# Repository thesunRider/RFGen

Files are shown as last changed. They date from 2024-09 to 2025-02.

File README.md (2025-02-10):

# RFGen




This is an open source DIY Square wave generator. There are two versions included: 
- Blue pill - (1Hz - 960Mhz)
- Atmega328p/Arduino (1Hz - 250Mhz)

### Schematics:

Arduino version
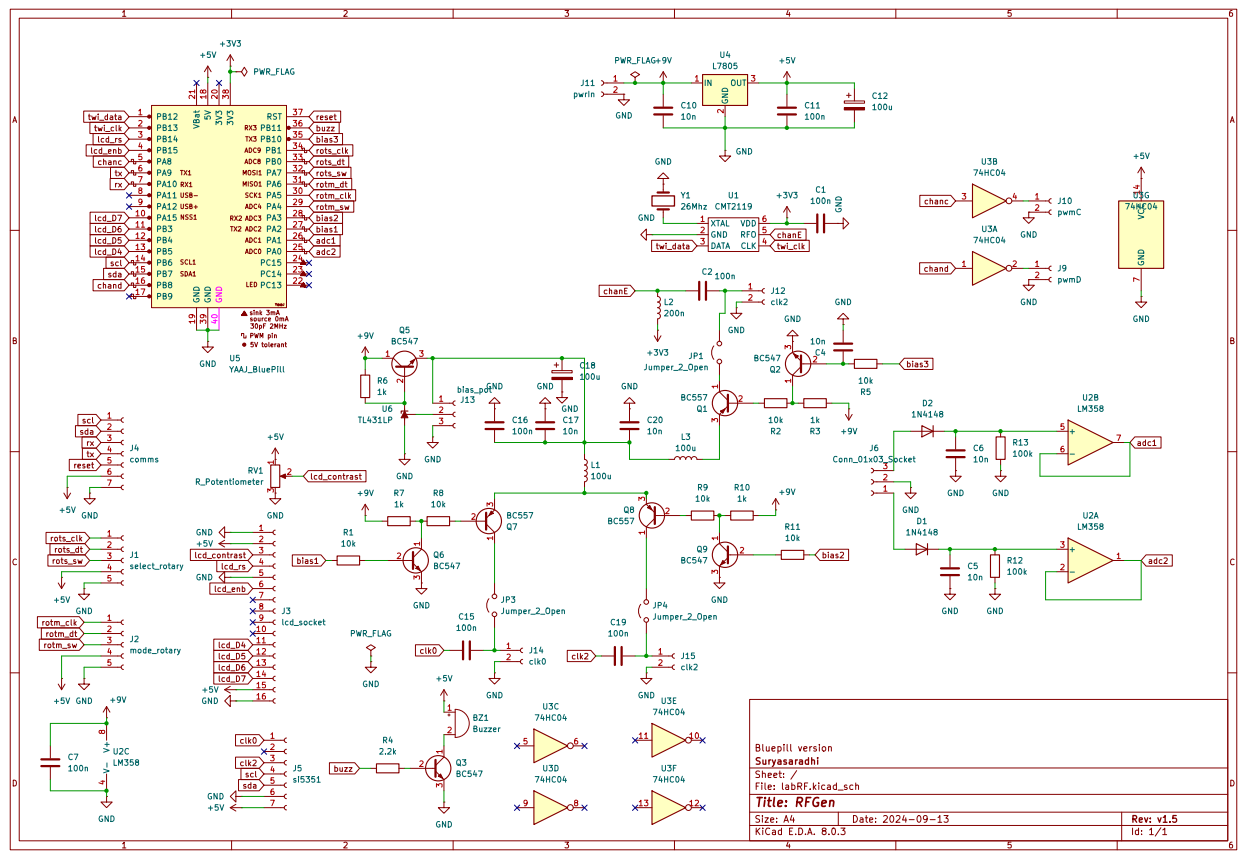
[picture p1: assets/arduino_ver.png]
arduino

Bluepill version
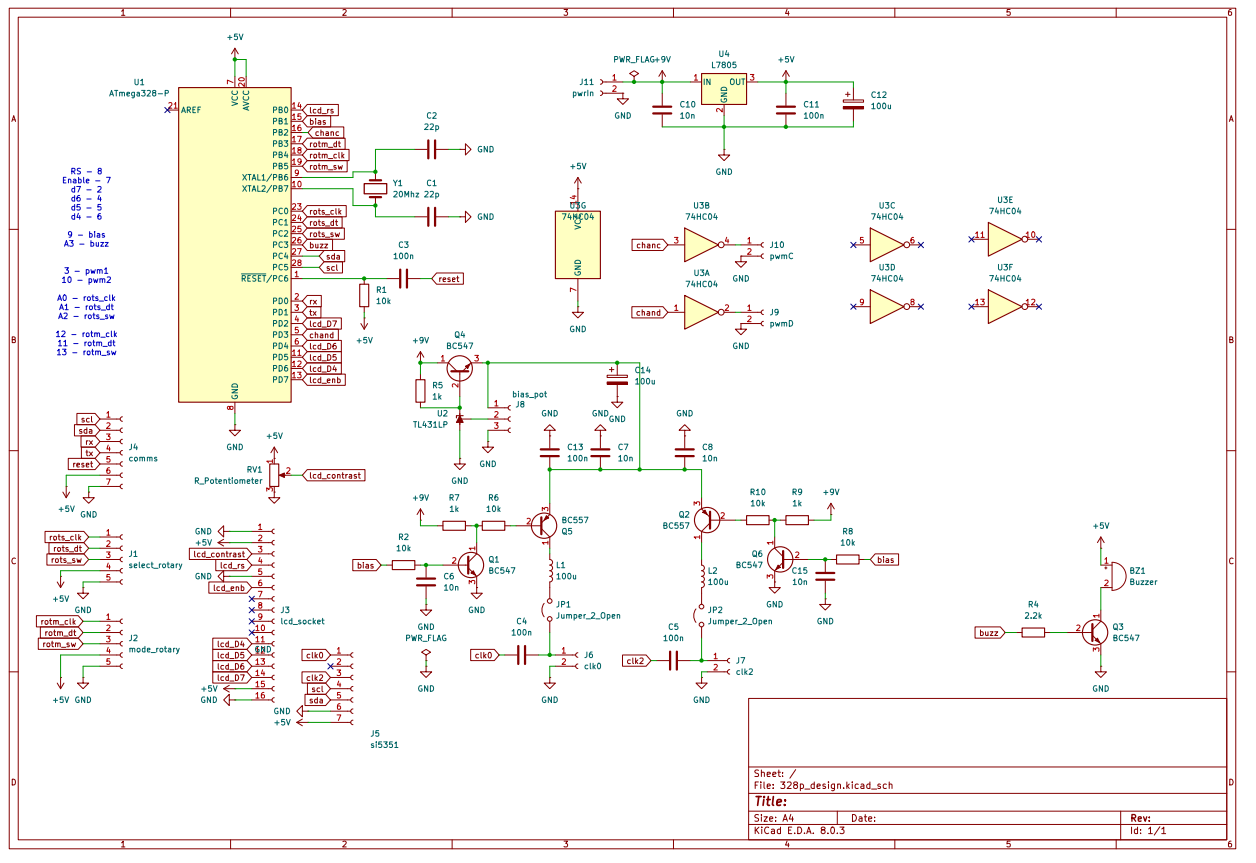
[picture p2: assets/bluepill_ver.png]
bluepill


- Si5351 - Channel A,B (1Khz - 250Mhz)
- CMT2119A - Channel E (only for bluepill version: 250Mhz - 960Mhz)

# Demo
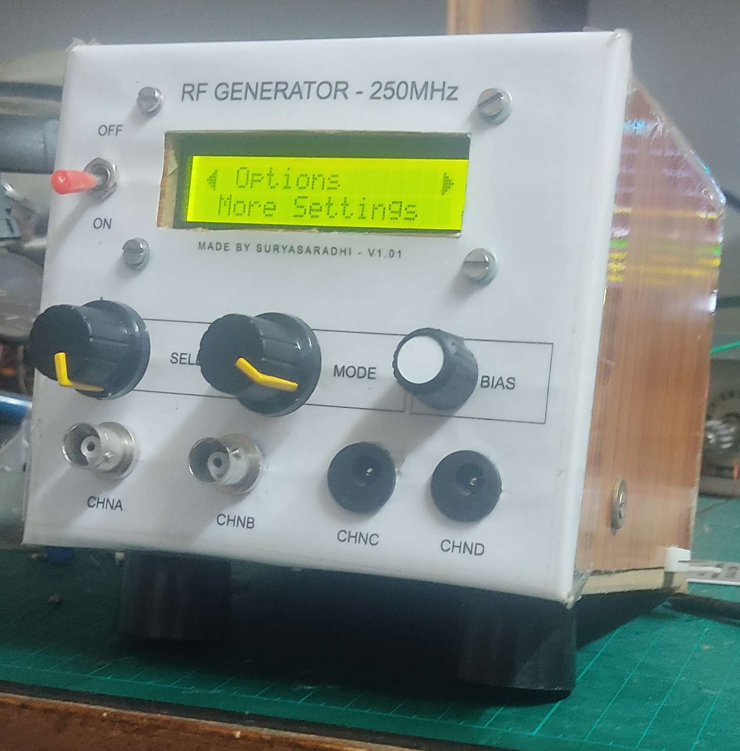
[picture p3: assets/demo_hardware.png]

Demo Video 

https://github.com/user-attachments/assets/bd40d5bd-5a4e-4a5a-9730-a542df9f6650

# Installation

- Upload 328p schematics for an Arduino based generator.
- Upload bluepill schematic for Bluepilll based generator.

> Gerber files attatched with kicad designs

# Usage

There is a bias tee included for these channels whose bias can be adjusted by the attached external potentiometer. 

Supply 9V on the power input, this is regulated to 5v by l7805

# Development

To program a soldered bluepill via USB kindly power off the device before connecting the USB. SInce UART pins are exposed you can program it via those headers too.

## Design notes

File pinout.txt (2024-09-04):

1   2   3   4   5
RX  RST TX SCL SDA

atmega

RS - 8
Enable - 7
d7 - 2
d6 - 4
d5 - 5
d4 - 6

9 - bias
A3 - buzz

3 - pwm1
10 - pwm2

A2,A1,A0
11,12,13

---- ALL PINS USED --------

LCD_RS  - 
LCD_E  - 
LCD_D4  - 
LCD_D5  - 
LCD_D6  - 
LCD_D7  - 
CLK 
DT
SW
CLK
DT
SW
WAV1
WAV2
BIASSWITCH
SCL - 
SDA - 
BUZZER
0 - RX
1 - TX
<-ADD->
TWO MORE switch

-> Total - 20

##PRGRAMMER PINS##
RX
RST
TX
SCL
SDA

LCD R/W  - ground
LCD VSS  - ground
LCD VDD  - 5V

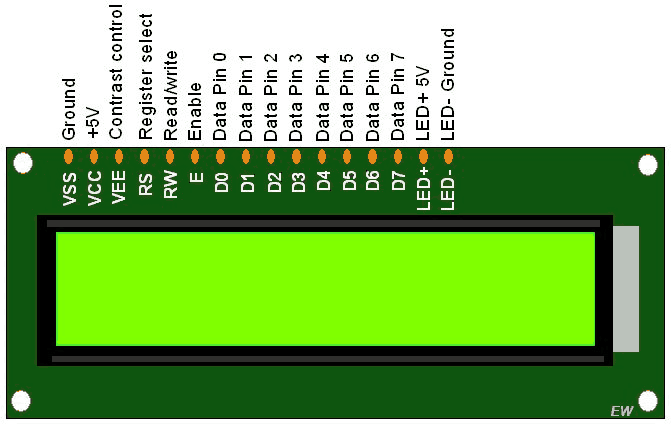
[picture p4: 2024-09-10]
pinouts/LCD16x2 Pins.webp

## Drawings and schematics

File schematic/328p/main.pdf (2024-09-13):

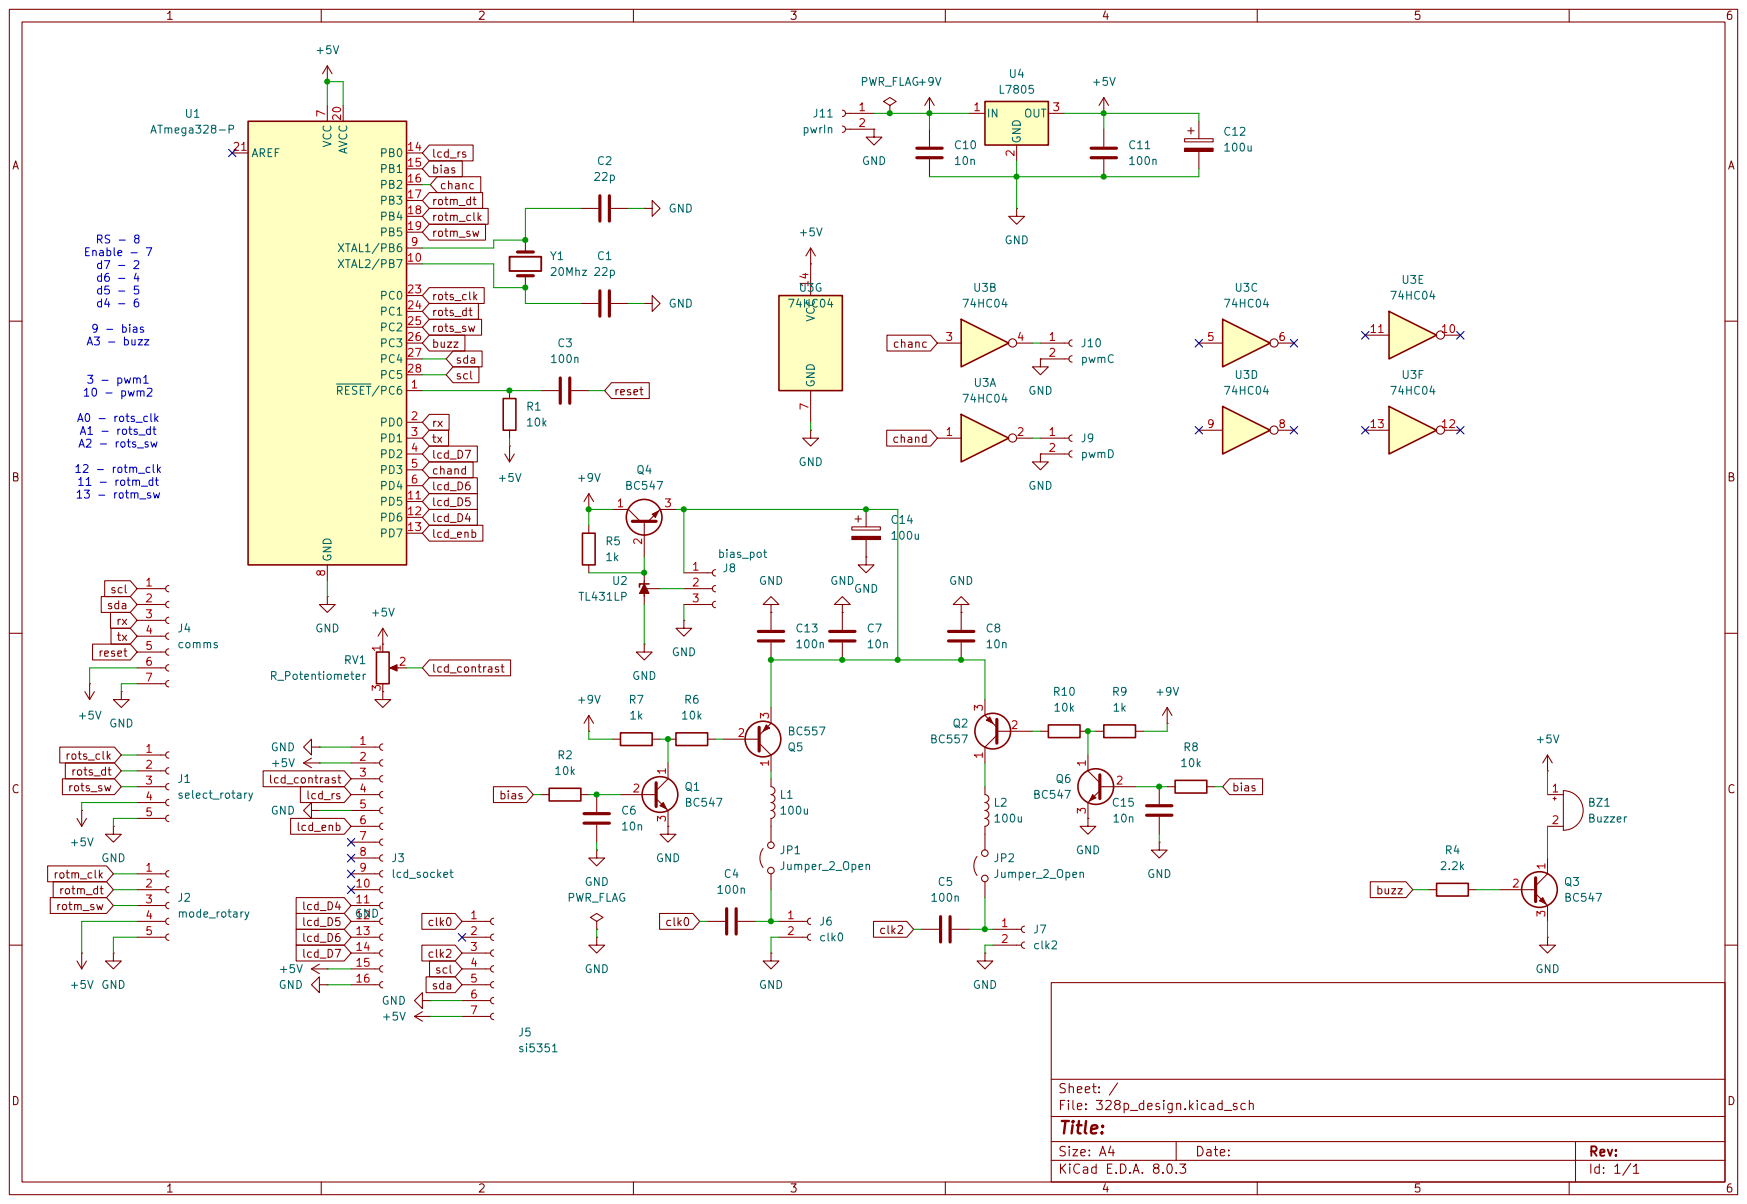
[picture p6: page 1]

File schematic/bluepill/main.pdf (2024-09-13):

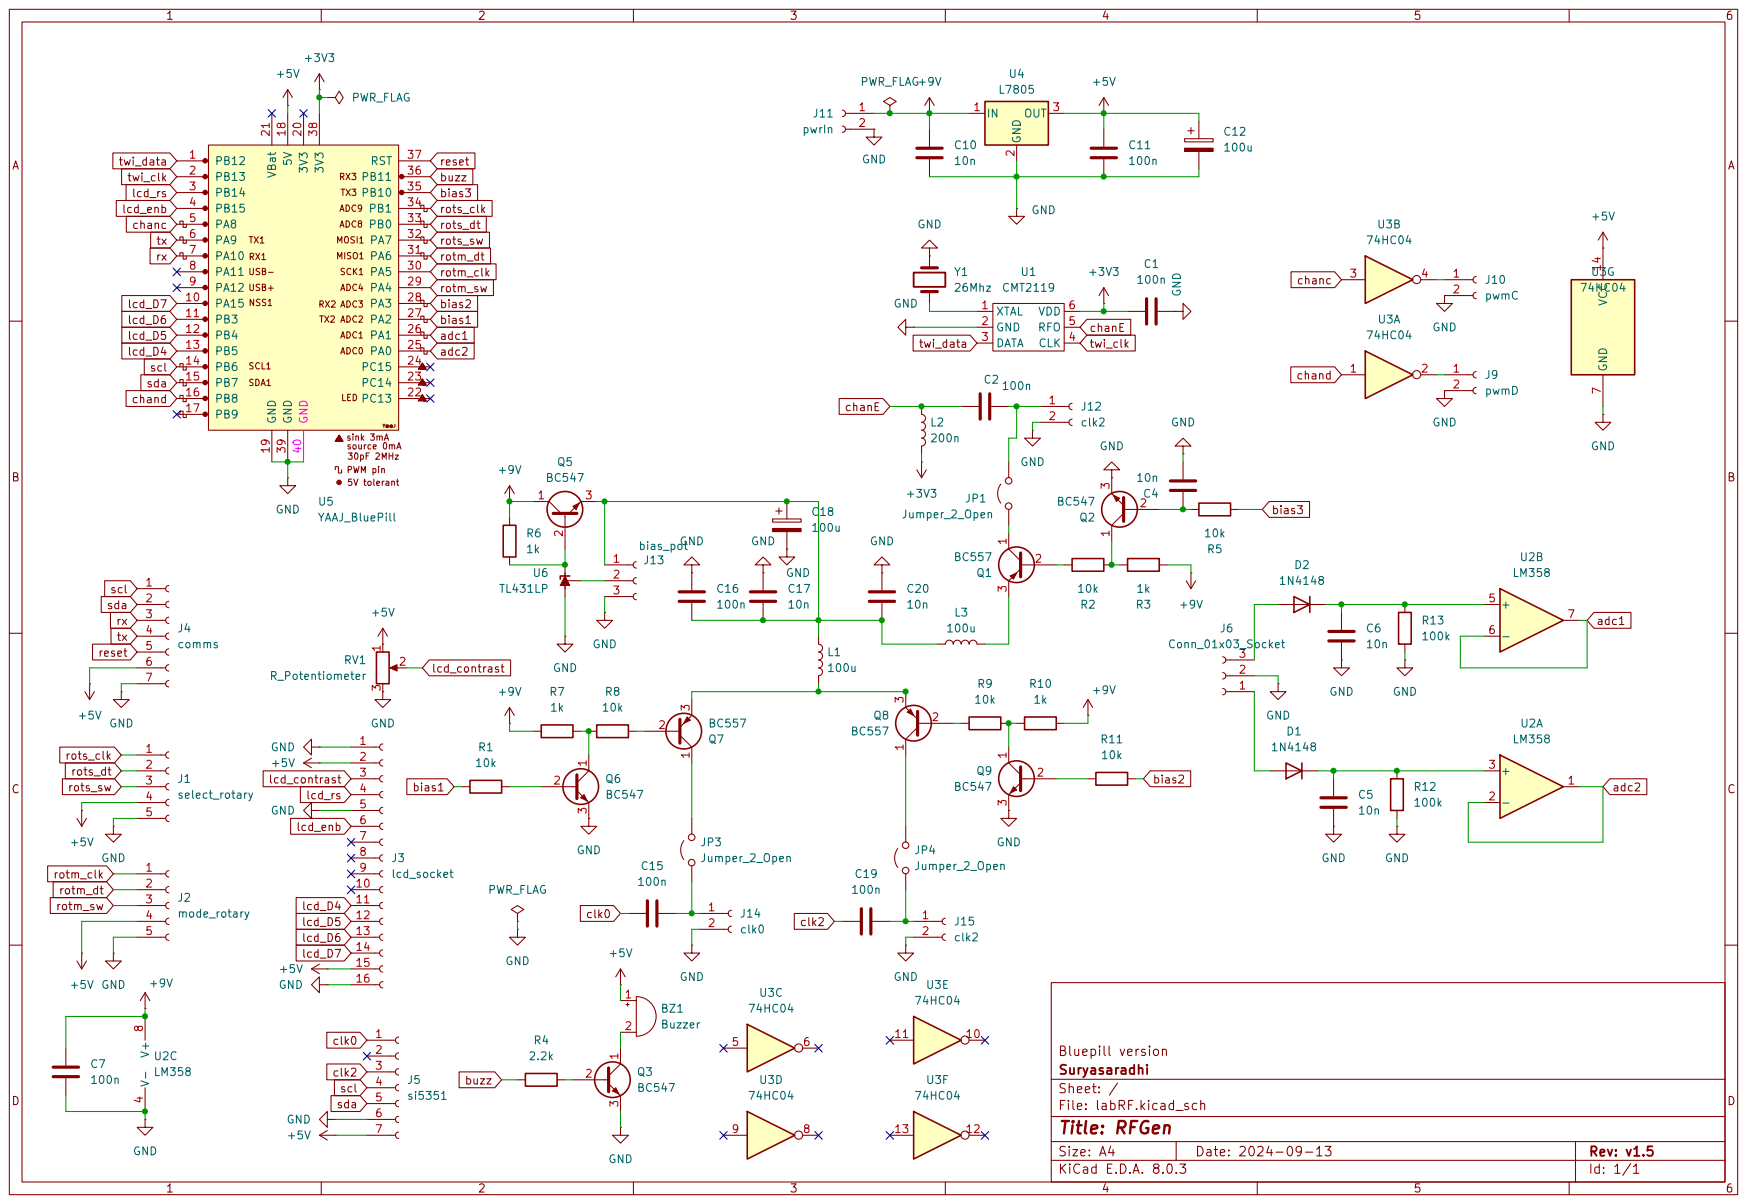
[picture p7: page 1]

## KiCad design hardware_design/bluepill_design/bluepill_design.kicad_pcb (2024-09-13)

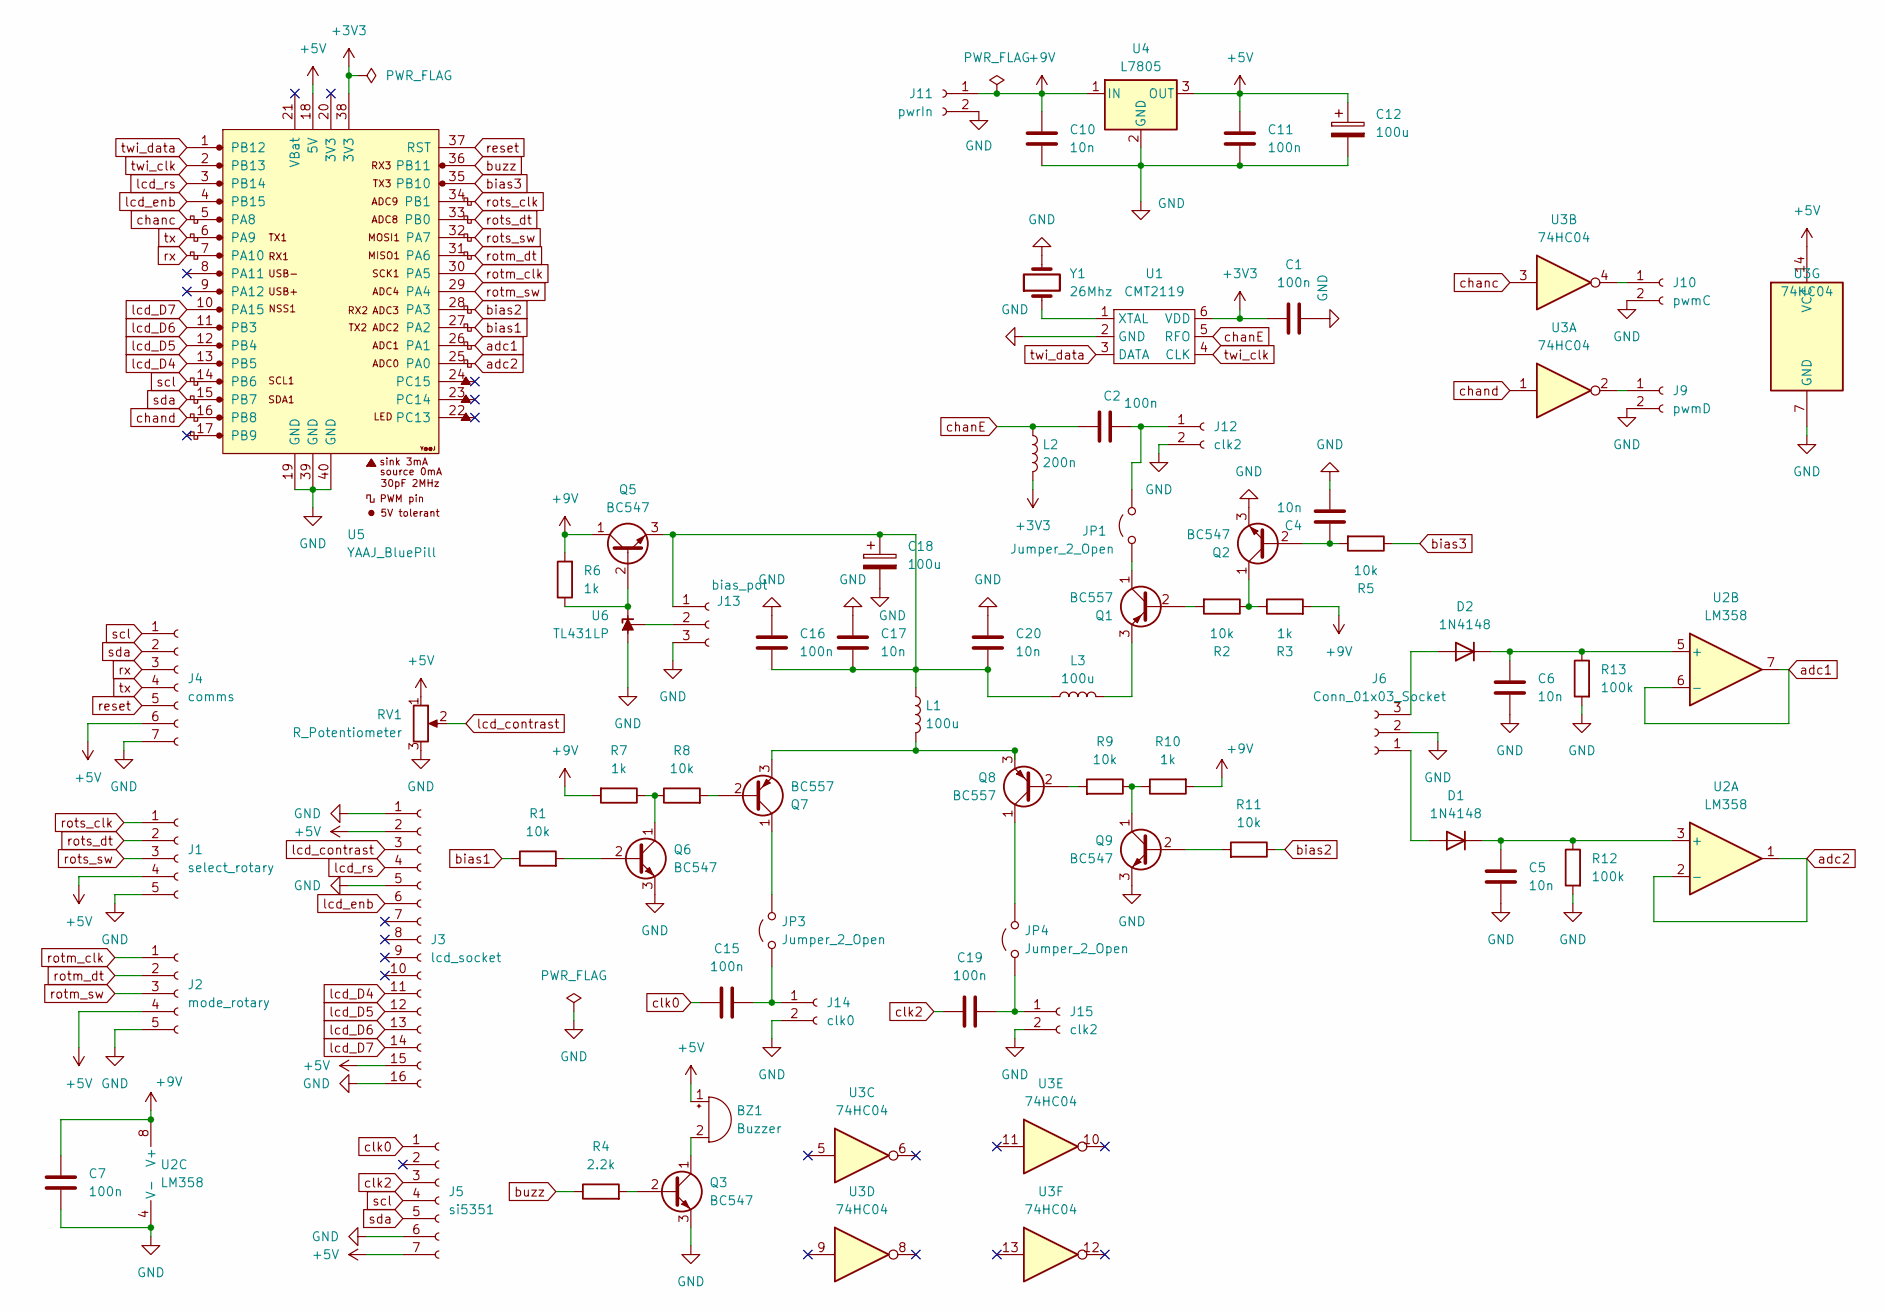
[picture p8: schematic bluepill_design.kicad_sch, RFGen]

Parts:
BZ1: Buzzer; Buzzer_D14mm_H7mm_P10mm
C1, C2, C7, C11, C15, C16, C19: 100n; C_Disc_D5.0mm_W2.5mm_P2.50mm
C4, C5, C6, C10, C17, C20: 10n; C_Disc_D5.0mm_W2.5mm_P2.50mm
C12, C18: 100u; CP_Radial_D8.0mm_P5.00mm
D1, D2: 1N4148; D_DO-35_SOD27_P7.62mm_Horizontal
J1: select_rotary; PinHeader_1x05_P2.54mm_Vertical
J2: mode_rotary; PinHeader_1x05_P2.54mm_Vertical
J3: lcd_socket; PinHeader_1x16_P2.54mm_Vertical
J4: comms; PinHeader_1x07_P2.54mm_Vertical
J5: si5351; PinHeader_1x07_P2.54mm_Vertical
J6: Conn_01x03_Socket; PinHeader_1x03_P2.54mm_Vertical
J9: pwmD; PinHeader_1x02_P2.54mm_Vertical
J10: pwmC; PinHeader_1x02_P2.54mm_Vertical
J11: pwrIn; PinHeader_1x02_P2.54mm_Vertical
J12, J15: clk2; PinHeader_1x02_P2.54mm_Vertical
J13: bias_pot; FanPinHeader_1x03_P2.54mm_Vertical
J14: clk0; PinHeader_1x02_P2.54mm_Vertical
JP1, JP3, JP4: Jumper_2_Open; PinHeader_1x02_P2.54mm_Vertical
L1, L3: 100u; L_Toroid_Vertical_L14.7mm_W8.6mm_P5.58mm_Pulse_KM-1
L2: 200n; L_Toroid_Vertical_L14.7mm_W8.6mm_P5.58mm_Pulse_KM-1
Q1, Q7, Q8: BC557; TO-92_Inline
Q2, Q3, Q5, Q6, Q9: BC547; TO-92_Inline
R1, R2, R5, R8, R9, R11: 10k; R_Axial_DIN0207_L6.3mm_D2.5mm_P10.16mm_Horizontal
R3, R6, R7, R10: 1k; R_Axial_DIN0207_L6.3mm_D2.5mm_P10.16mm_Horizontal
R4: 2.2k; R_Axial_DIN0207_L6.3mm_D2.5mm_P10.16mm_Horizontal
R12, R13: 100k; R_Axial_DIN0207_L6.3mm_D2.5mm_P10.16mm_Horizontal
RV1: R_Potentiometer; Potentiometer_Bourns_3386P_Vertical
U1: CMT2119; SOT-23-6_Handsoldering
U2: LM358; DIP-8_W7.62mm
U3: 74HC04; DIP-14_W7.62mm
U4: L7805; TO-220-3_Vertical
U5: YAAJ_BluePill; YAAJ_BluePill_2
U6: TL431LP; TO-92_Inline
Y1: 26Mhz; Crystal_HC49-U_Vertical

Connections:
+3V3: C1.2, L2.2, U1.6 (VDD), U5.38 (3V3)
+5V: BZ1.1 (+), C11.2, C12.1, J1.4, J2.4, J3.2, J3.15, J4.6, J5.7, RV1.1, U3.14 (VCC), U4.3 (OUT), U5.18 (5V)
+9V: C7.2, C10.2, J11.1, Q5.1 (C), R3.2, R6.2, R7.2, R10.2, U2.8 (V+), U4.1 (IN)
GND: C1.1, C4.2, C5.2, C6.2, C7.1, C10.1, C11.1, C12.2, C16.1, C17.1, C18.2, C20.1, J1.5, J2.5, J3.1, J3.5, J3.16, J4.7, J5.6, J6.2, J9.2, J10.2, J11.2, J12.2, J13.3, J14.2, J15.2, Q2.3 (E), Q3.3 (E), Q6.3 (E), Q9.3 (E), R12.2, R13.2, RV1.3, U1.2 (GND), U2.4 (V-), U3.7 (GND), U4.2 (GND), U5.19 (GND), U5.39 (GND), U5.40 (GND), U6.2 (A), Y1.2
unnamed: BZ1.2 (-), Q3.1 (C)
unnamed: D1.2 (A), J6.1
unnamed: C5.1, D1.1 (K), R12.1, U2.3 (+)
unnamed: D2.2 (A), J6.3
unnamed: C6.1, D2.1 (K), R13.1, U2.5 (+)
unnamed: J9.1, U3.2
unnamed: J10.1, U3.4
unnamed: C2.2, J12.1, JP1.1 (A)
unnamed: C16.2, C17.2, C18.1, C20.2, J13.1, L1.1, L3.1, Q5.3 (E)
unnamed: J13.2, U6.1 (REF)
unnamed: C15.2, J14.1, JP3.1 (A)
unnamed: C19.2, J15.1, JP4.1 (A)
unnamed: JP1.2 (B), Q1.1 (C)
unnamed: JP3.2 (B), Q7.1 (C)
unnamed: JP4.2 (B), Q8.1 (C)
unnamed: Q1.2 (B), R2.2
unnamed: L3.2, Q1.3 (E)
unnamed: C4.1, Q2.2 (B), R5.2
unnamed: Q2.1 (C), R2.1, R3.1
unnamed: Q3.2 (B), R4.2
unnamed: Q5.2 (B), R6.1, U6.3 (K)
unnamed: Q6.2 (B), R1.2
unnamed: Q6.1 (C), R7.1, R8.1
unnamed: Q7.2 (B), R8.2
unnamed: L1.2, Q7.3 (E), Q8.3 (E)
unnamed: Q8.2 (B), R9.2
unnamed: Q9.2 (B), R11.2
unnamed: Q9.1 (C), R9.1, R10.1
unnamed: U1.1 (XTAL), Y1.1
adc1: U2.6 (-), U2.7, U5.26 (PA1)
adc2: U2.1, U2.2 (-), U5.25 (PA0)
bias1: R1.1, U5.27 (PA2)
bias2: R11.1, U5.28 (PA3)
bias3: R5.1, U5.35 (PB10)
buzz: R4.1, U5.36 (PB11)
chanE: C2.1, L2.1, U1.5 (RFO)
chanc: U3.3, U5.5 (PA8)
chand: U3.1, U5.16 (PB8)
clk0: C15.1, J5.1
clk2: C19.1, J5.3
lcd_D4: J3.11, U5.13 (PB5)
lcd_D5: J3.12, U5.12 (PB4)
lcd_D6: J3.13, U5.11 (PB3)
lcd_D7: J3.14, U5.10 (PA15)
lcd_contrast: J3.3, RV1.2
lcd_enb: J3.6, U5.4 (PB15)
lcd_rs: J3.4, U5.3 (PB14)
reset: J4.5, U5.37 (RST)
rotm_clk: J2.1, U5.30 (PA5)
rotm_dt: J2.2, U5.31 (PA6)
rotm_sw: J2.3, U5.29 (PA4)
rots_clk: J1.1, U5.34 (PB1)
rots_dt: J1.2, U5.33 (PB0)
rots_sw: J1.3, U5.32 (PA7)
rx: J4.3, U5.7 (PA10)
scl: J4.1, J5.4, U5.14 (PB6)
sda: J4.2, J5.5, U5.15 (PB7)
twi_clk: U1.4 (CLK), U5.2 (PB13)
twi_data: U1.3 (DATA), U5.1 (PB12)
tx: J4.4, U5.6 (PA9)

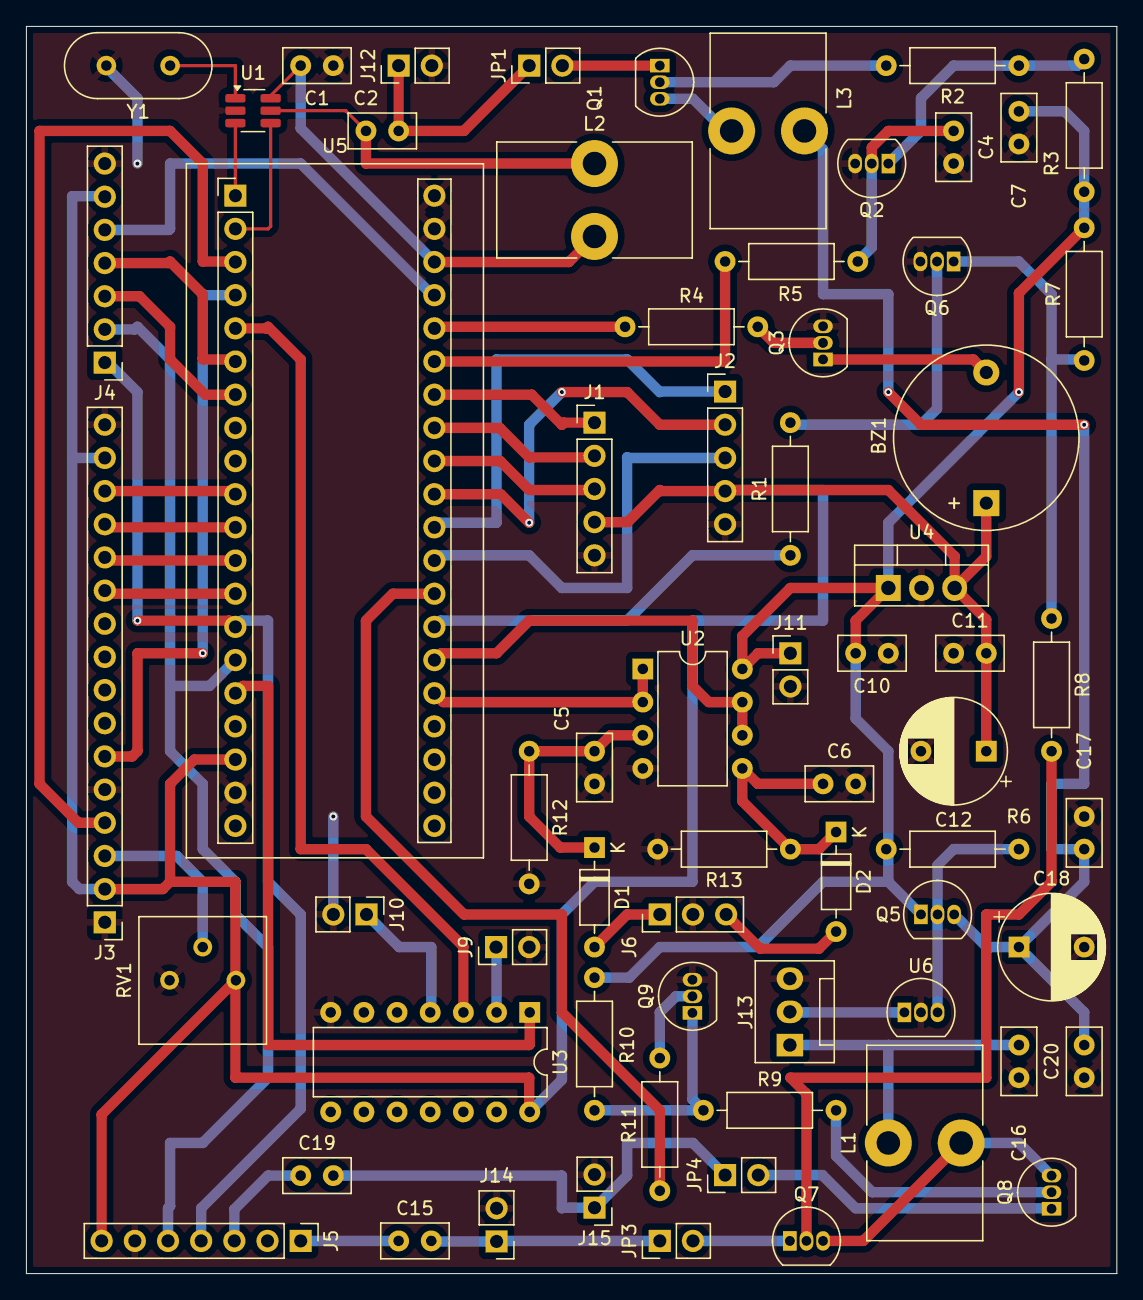
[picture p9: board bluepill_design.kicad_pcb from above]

Board: 2 copper layers, 83.5 x 95.5 mm, 66 parts (0 on the bottom side), 64 nets.

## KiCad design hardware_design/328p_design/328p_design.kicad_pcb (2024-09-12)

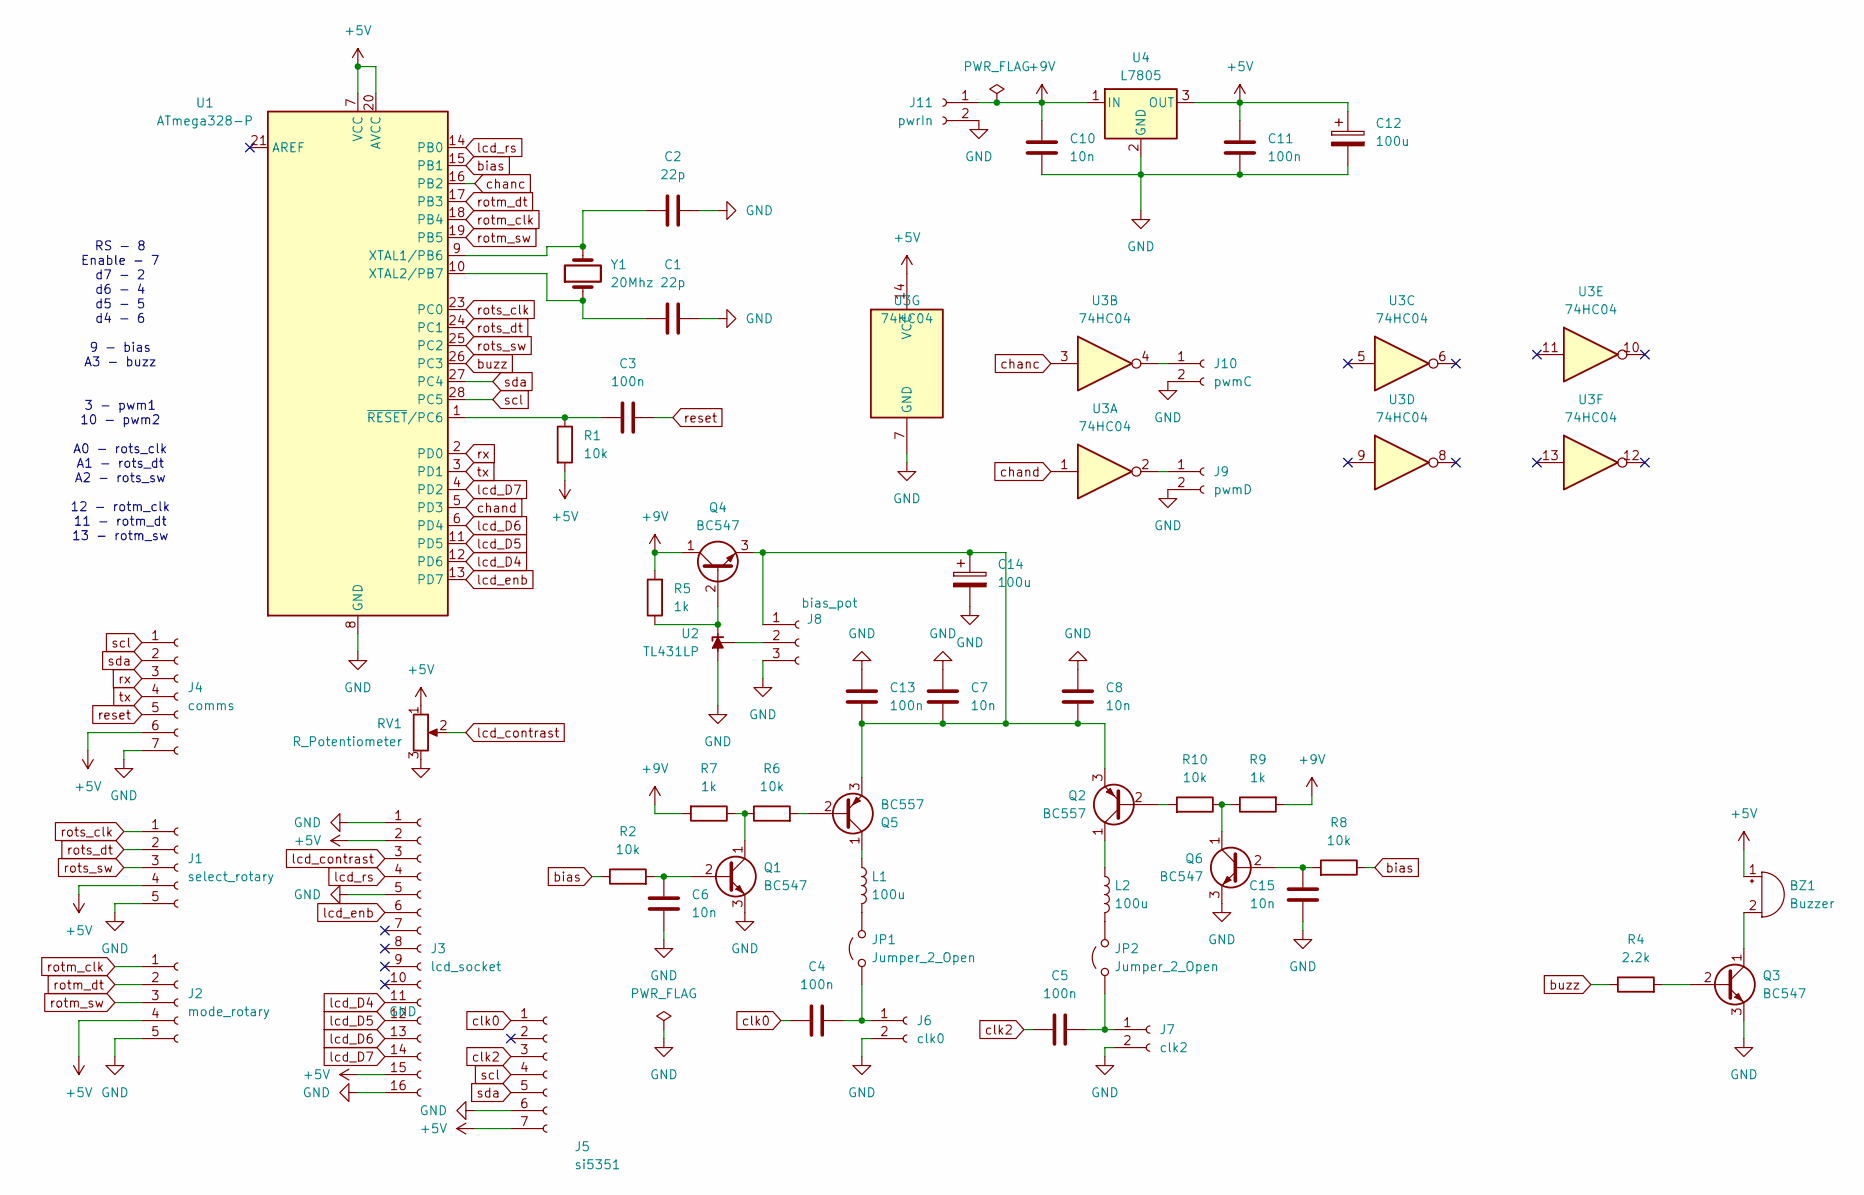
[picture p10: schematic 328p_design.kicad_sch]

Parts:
BZ1: Buzzer; Buzzer_D14mm_H7mm_P10mm
C1, C2: 22p; C_Disc_D5.0mm_W2.5mm_P2.50mm
C3, C4, C5, C11, C13: 100n; C_Disc_D5.0mm_W2.5mm_P2.50mm
C6, C7, C8, C10, C15: 10n; C_Disc_D5.0mm_W2.5mm_P2.50mm
C12, C14: 100u; CP_Radial_D8.0mm_P5.00mm
J1: select_rotary; PinHeader_1x05_P2.54mm_Vertical
J2: mode_rotary; PinHeader_1x05_P2.54mm_Vertical
J3: lcd_socket; PinHeader_1x16_P2.54mm_Vertical
J4: comms; PinHeader_1x07_P2.54mm_Vertical
J5: si5351; PinHeader_1x07_P2.54mm_Vertical
J6: clk0; PinHeader_1x02_P2.54mm_Vertical
J7: clk2; PinHeader_1x02_P2.54mm_Vertical
J8: bias_pot; FanPinHeader_1x03_P2.54mm_Vertical
J9: pwmD; PinHeader_1x02_P2.54mm_Vertical
J10: pwmC; PinHeader_1x02_P2.54mm_Vertical
J11: pwrIn; PinHeader_1x02_P2.54mm_Vertical
JP1, JP2: Jumper_2_Open; PinHeader_1x02_P2.54mm_Vertical
L1, L2: 100u; L_Toroid_Vertical_L14.7mm_W8.6mm_P5.58mm_Pulse_KM-1
Q1, Q3, Q4, Q6: BC547; TO-92_Inline
Q2, Q5: BC557; TO-92_Inline
R1, R2, R6, R8, R10: 10k; R_Axial_DIN0207_L6.3mm_D2.5mm_P10.16mm_Horizontal
R4: 2.2k; R_Axial_DIN0207_L6.3mm_D2.5mm_P10.16mm_Horizontal
R5, R7, R9: 1k; R_Axial_DIN0207_L6.3mm_D2.5mm_P10.16mm_Horizontal
RV1: R_Potentiometer; Potentiometer_Bourns_3386P_Vertical
U1: ATmega328-P; DIP-28_W7.62mm
U2: TL431LP; TO-92_Inline
U3: 74HC04; DIP-14_W7.62mm
U4: L7805; TO-220-3_Vertical
Y1: 20Mhz; Crystal_HC49-U_Vertical

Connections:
+5V: BZ1.1 (+), C11.2, C12.1, J1.4, J2.4, J3.2, J3.15, J4.6, J5.7, R1.2, RV1.1, U1.7 (VCC), U1.20 (AVCC), U3.14 (VCC), U4.3 (OUT)
+9V: C10.2, J11.1, Q4.1 (C), R5.2, R7.2, R9.2, U4.1 (IN)
GND: C1.2, C2.2, C6.2, C7.1, C8.1, C10.1, C11.1, C12.2, C13.1, C14.2, C15.2, J1.5, J2.5, J3.1, J3.5, J3.16, J4.7, J5.6, J6.2, J7.2, J8.3, J9.2, J10.2, J11.2, Q1.3 (E), Q3.3 (E), Q6.3 (E), RV1.3, U1.8 (GND), U1.22 (GND), U2.2 (A), U3.7 (GND), U4.2 (GND)
unnamed: BZ1.2 (-), Q3.1 (C)
unnamed: C4.2, J6.1, JP1.1 (A)
unnamed: C5.2, J7.1, JP2.1 (A)
unnamed: C7.2, C8.2, C13.2, C14.1, J8.1, Q2.3 (E), Q4.3 (E), Q5.3 (E)
unnamed: J8.2, U2.1 (REF)
unnamed: J9.1, U3.2
unnamed: J10.1, U3.4
unnamed: JP1.2 (B), L1.2
unnamed: JP2.2 (B), L2.2
unnamed: C6.1, Q1.2 (B), R2.2
unnamed: Q1.1 (C), R6.1, R7.1
unnamed: Q2.2 (B), R10.2
unnamed: L2.1, Q2.1 (C)
unnamed: Q3.2 (B), R4.2
unnamed: Q4.2 (B), R5.1, U2.3 (K)
unnamed: Q5.2 (B), R6.2
unnamed: L1.1, Q5.1 (C)
unnamed: C15.1, Q6.2 (B), R8.2
unnamed: Q6.1 (C), R9.1, R10.1
unnamed: C2.1, U1.9 (XTAL1/PB6), Y1.2
unnamed: C1.1, U1.10 (XTAL2/PB7), Y1.1
unnamed: C3.1, R1.1, U1.1 (~RESET/PC6)
bias: R2.1, R8.1, U1.15 (PB1)
buzz: R4.1, U1.26 (PC3)
chanc: U1.16 (PB2), U3.3
chand: U1.5 (PD3), U3.1
clk0: C4.1, J5.1
clk2: C5.1, J5.3
lcd_D4: J3.11, U1.12 (PD6)
lcd_D5: J3.12, U1.11 (PD5)
lcd_D6: J3.13, U1.6 (PD4)
lcd_D7: J3.14, U1.4 (PD2)
lcd_contrast: J3.3, RV1.2
lcd_enb: J3.6, U1.13 (PD7)
lcd_rs: J3.4, U1.14 (PB0)
reset: C3.2, J4.5
rotm_clk: J2.1, U1.18 (PB4)
rotm_dt: J2.2, U1.17 (PB3)
rotm_sw: J2.3, U1.19 (PB5)
rots_clk: J1.1, U1.23 (PC0)
rots_dt: J1.2, U1.24 (PC1)
rots_sw: J1.3, U1.25 (PC2)
rx: J4.3, U1.2 (PD0)
scl: J4.1, J5.4, U1.28 (PC5)
sda: J4.2, J5.5, U1.27 (PC4)
tx: J4.4, U1.3 (PD1)

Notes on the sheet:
RS - 8 Enable - 7 d7 - 2 d6 - 4 d5 - 5 d4 - 6 9 - bias A3 - buzz 3 - pwm1 10 - pwm2 A0 - rots_clk A1 - rots_dt A2 - rots_sw 12 - rotm_clk 11 - rotm_dt 13 - rotm_sw

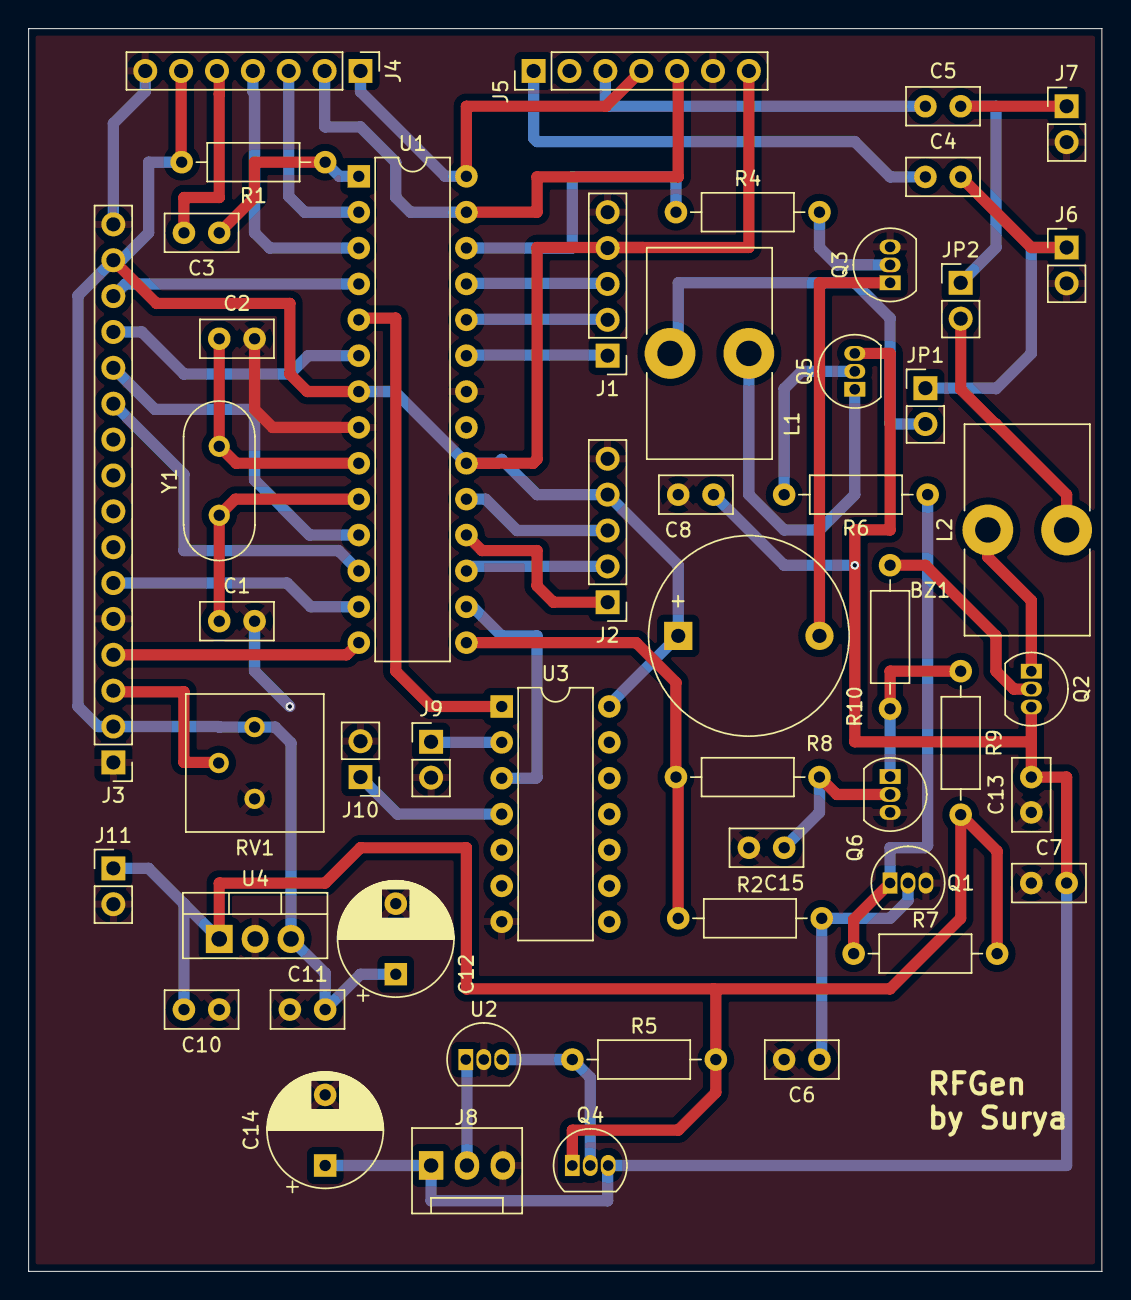
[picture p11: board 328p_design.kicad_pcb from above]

Board: 2 copper layers, 76.0 x 88.0 mm, 51 parts (0 on the bottom side), 49 nets.

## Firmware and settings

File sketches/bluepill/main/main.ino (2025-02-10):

#define USING_MICROS_RESOLUTION true  //false

#include "STM32_PWM.h"
#define boolean bool

#define HW_TIMER_INTERVAL_US 10L

#include <LiquidCrystal.h>
#include <Rotary.h>
#include <si5351mcu.h>
#include <EButton.h>

#include "src/RFM119/HopeDuino_CMT211xA.h"



/*
1   2   3   4   5
RX  RST TX SCL SDA

bluepill

RS - 8
Enable - 7
d7 - 2
d6 - 4
d5 - 5
d4 - 6

9 - bias
A3 - buzz


3 - pwm1
10 - pwm2

A0 - rots_clk
A1 - rots_dt
A2 - rots_sw

12 - rotm_clk
11 - rotm_dt
13 - rotm_sw
*/

#define TWI_DAT PB12
#define TWI_CLK PB13

#define BIAS_PIN1 PA2
#define BIAS_PIN2 PA3
#define BIAS_PIN3 PB10
#define BUZZ_PIN PB11
#define PWM_PIN2 PB8
#define PWM_PIN1 PA8

#define ROT_SELECT_CLK PB1
#define ROT_SELECT_DT PB0
#define ROT_SELECT_SW PA7

#define ROT_MODE_CLK PA5
#define ROT_MODE_DT PA6
#define ROT_MODE_SW PA4


// Pin mapping for the display:
const byte LCD_RS = PB14;
const byte LCD_E = PB15;
const byte LCD_D4 = PB5;
const byte LCD_D5 = PB4;
const byte LCD_D6 = PB3;
const byte LCD_D7 = PA15;
//LCD R/W pin to ground
//10K potentiometer wiper to VO
LiquidCrystal lcd(LCD_RS, LCD_E, LCD_D4, LCD_D5, LCD_D6, LCD_D7);


// lib instantiation as "Si"
Si5351mcu Si;

Rotary rselect = Rotary(ROT_SELECT_CLK, ROT_SELECT_DT);
Rotary rmode = Rotary(ROT_MODE_CLK, ROT_MODE_DT);

EButton rot_select_button(ROT_SELECT_SW, true);
EButton rot_mode_button(ROT_MODE_SW, true);


unsigned long pwm1freq;
int pwm1duty;

unsigned long pwm2freq;
int pwm2duty;

#define SPLASH_DELAY 700
int buzz_duration = 30;

// ----- lcd declarations --------

#define LEFT_OPT 0
#define RIGHT_OPT 1
#define RIGHT_ARW 2
#define LEFT_ARW 3
#define BACK_MENU 4
#define BIAS_MENU 5

byte left_options[] = {
  B00000,
  B00001,
  B00011,
  B00111,
  B01111,
  B00111,
  B00011,
  B00001
};

byte right_options[] = {
  B00000,
  B10000,
  B11000,
  B11100,
  B11110,
  B11100,
  B11000,
  B10000
};

byte right_arrow[] = {
  B00000,
  B00100,
  B00010,
  B11111,
  B00010,
  B00100,
  B00000,
  B00000
};

byte left_arrow[] = {
  B00000,
  B00100,
  B01000,
  B11111,
  B01000,
  B00100,
  B00000,
  B00000
};

byte back_menu[] = {
  B00000,
  B00100,
  B01110,
  B10101,
  B00100,
  B00100,
  B11100,
  B00000
};

byte bias_char[] = {
  B00000,
  B10000,
  B10001,
  B10000,
  B11001,
  B10101,
  B11001,
  B00000
};

cmt211xaClass radio;

byte str[31] = {
  0xAA,
  0xAA,
  0xAA,
  0xAA,
  0xAA,
  0xAA,
  0xAA,
  0xAA,
  0x2D,
  0xD4,
  'H',
  'o',
  'p',
  'e',
  'R',
  'F',
  ' ',
  'R',
  'F',
  'M',
  ' ',
  'C',
  'O',
  'B',
  'R',
  'F',
  'M',
  '1',
  '1',
  '9',
  'S',
};

word CfgTbl[21] = {
0x007F,
0x5000,
0x0000,
0x0000,
0x0000,
0xF000,
0x0000,
0xBB13,
0x4200,
0x0000,
0x2401,
0x01B0,
0x8000,
0x0006,
0xFFFF,
0x0020,
0x5F1E,
0x22D6,
0x0E13,
0x0019,
0x2000,
};

PinName pinNameToUse_PWM1 = digitalPinToPinName(PWM_PIN1);
TIM_TypeDef *Instanc_PWM1 = (TIM_TypeDef *)pinmap_peripheral(pinNameToUse_PWM1, PinMap_PWM);
uint32_t PWM_channel1 = STM_PIN_CHANNEL(pinmap_function(pinNameToUse_PWM1, PinMap_PWM));

PinName pinNameToUse_PWM2 = digitalPinToPinName(PWM_PIN2);
TIM_TypeDef *Instanc_PWM2 = (TIM_TypeDef *)pinmap_peripheral(pinNameToUse_PWM2, PinMap_PWM);
uint32_t PWM_channel2 = STM_PIN_CHANNEL(pinmap_function(pinNameToUse_PWM2, PinMap_PWM));


HardwareTimer *PWM1;
HardwareTimer *PWM2;

void setPWMfrequency(int chn, uint32_t freq, int duty) {
  if (chn == 0) {
    if (PWM1)
      delete PWM1;

    PWM1 = new HardwareTimer(Instanc_PWM1);
    PWM1->setPWM(PWM_channel1, PWM_PIN1, freq, duty);
  } else {
    if (PWM2)
      delete PWM2;

    PWM2 = new HardwareTimer(Instanc_PWM2);
    PWM2->setPWM(PWM_channel2, PWM_PIN2, freq, duty);
  }
}


#define NUM_PAGES 6
#define PAGE_CHNA 0
#define PAGE_CHNB 1
#define PAGE_CHNC 2
#define PAGE_CHND 3
#define PAGE_SWEP 4
#define PAGE_PROG 5
#define PAGE_SET 6

#define SELECT_SW 0
#define MODE_SW 1

bool switch_sel_status = 0;
bool switch_mode_status = 0;

void formatfloat(float num, int totalWidth, int precision, char *buffer) {
  int integerPart = static_cast<int>(num);  // Extract integer part
  float decimalPart = num - integerPart;    // Extract decimal part


  // Multiply decimal part to convert it into an integer (e.g., 0.34 -> 34)
  for (int i = 0; i < precision; ++i) {
    decimalPart *= 10;
  }

  int decimalInt = static_cast<int>(decimalPart);  // Convert decimal to integer

  // Convert integer and decimal parts into a single string manually
  for (int i = 0; i < strlen(buffer); ++i) {
    buffer[i] = '0';
  }

  int numDigits = 1;
  if (integerPart != 0)
    numDigits = floor(log10(integerPart) + 1);


  // Calculate the number of leading zeros needed
  int leadingZeros = totalWidth - (numDigits + precision);

  // Add leading zeros
  for (int i = 0; i < leadingZeros; ++i) {
    buffer[i] = '0';
  }

  // Add integer part to buffer
  int index = leadingZeros;
  int tempInt = integerPart;
  if (tempInt != 0)
    for (int i = numDigits - 1; i >= 0; --i) {
      buffer[index + i] = '0' + (tempInt % 10);
      tempInt /= 10;
    }
  index += numDigits;

  // Add decimal point
  buffer[index++] = '.';

  // Add decimal part to buffer
  tempInt = decimalInt;
  if (decimalInt != 0)
    for (int i = precision - 1; i >= 0; --i) {
      buffer[index + i] = '0' + (tempInt % 10);
      tempInt /= 10;
    }

  buffer[index + precision] = '\0';  // Null-terminate the string
}

bool was_clicked(int switch_sel, bool consume) {
  int switch_temp_status;
  if (switch_sel == SELECT_SW) {
    switch_temp_status = switch_sel_status;
    if (consume)
      switch_sel_status = 0;
  } else {
    switch_temp_status = switch_mode_status;
    if (consume)
      switch_mode_status = 0;
  }
  return switch_temp_status;
}

void click_select(EButton &btn) {
  switch_sel_status = 1;
  digitalWrite(BUZZ_PIN, HIGH);
  delay(buzz_duration);
  digitalWrite(BUZZ_PIN, LOW);
}

void click_mode(EButton &btn) {
  switch_mode_status = 1;
  digitalWrite(BUZZ_PIN, HIGH);
  delay(buzz_duration);
  digitalWrite(BUZZ_PIN, LOW);
}


int options_page() {
  delay(100);
  lcd.clear();
  lcd.noCursor();
  lcd.setCursor(0, 0);
  lcd.write(byte(LEFT_OPT));
  lcd.setCursor(15, 0);
  lcd.write(byte(RIGHT_OPT));

  int option_selected = 0;

  lcd.setCursor(1, 0);
  lcd.print(F("  CHANNEL A"));
  lcd.setCursor(0, 1);
  lcd.print(F(" RF MW-VHF O/P"));

  rot_select_button.tick();
  rot_mode_button.tick();

  while (!was_clicked(SELECT_SW, true)) {
    // put your main code here, to run repeatedly:
    unsigned char rselect_event = rselect.process();
    unsigned char rmode_event = rmode.process();

    rot_select_button.tick();
    rot_mode_button.tick();

    //play sound
    if (rselect_event || rmode_event && buzz_duration > 0) {
      digitalWrite(BUZZ_PIN, HIGH);
      delay(buzz_duration);
      digitalWrite(BUZZ_PIN, LOW);
    }

    if (rselect_event) {
      rselect_event == DIR_CW ? option_selected++ : option_selected--;
      if (option_selected < 0)
        option_selected = NUM_PAGES;
      if (option_selected > NUM_PAGES)
        option_selected = 0;

      switch (option_selected) {
        case PAGE_CHNA:
          lcd.setCursor(1, 0);
          lcd.print(F("  CHANNEL A  "));
          lcd.setCursor(0, 1);
          lcd.print(F(" RF MW-VHF O/P"));
          break;

        case PAGE_CHNB:
          lcd.setCursor(1, 0);
          lcd.print(F("  CHANNEL B  "));
          lcd.setCursor(0, 1);
          lcd.print(F(" RF MW-VHF O/P"));
          break;

        case PAGE_CHNC:
          lcd.setCursor(1, 0);
          lcd.print(F("  CHANNEL C  "));
          lcd.setCursor(0, 1);
          lcd.print(F(" PWM 0-MW O/P "));
          break;

        case PAGE_CHND:
          lcd.setCursor(1, 0);
          lcd.print(F("  CHANNEL D  "));
          lcd.setCursor(0, 1);
          lcd.print(F(" PWM 0-MW O/P "));
          break;

        case PAGE_SWEP:
          lcd.setCursor(1, 0);
          lcd.print(F("  Sweep    "));
          lcd.setCursor(0, 1);
          lcd.print(F(" Freq Sweeper  "));
          break;

        case PAGE_PROG:
          lcd.setCursor(1, 0);
          lcd.print(F("  Prog mode  "));
          lcd.setCursor(0, 1);
          lcd.print(F(" Prog using i2c"));
          break;

        case PAGE_SET:
          lcd.setCursor(1, 0);
          lcd.print(F("  Options   "));
          lcd.setCursor(0, 1);
          lcd.print(F(" More Settings "));
          break;



        default:
          break;
      }
    }
  }
  switch_sel_status = 0;
  switch_mode_status = 0;

  Serial.println(option_selected);
  return option_selected;
}

#define OPTIONS_CHNA 5
#define CHN_LFFREQ 0
#define CHN_HFFREQ 1
#define CHN_ENABLE 2
#define CHN_PWR 5
#define CHN_BIAS 3
#define BACK_OPTION 4

int lffreq_chna = 1000;
float hffreq_chna = 1;
bool chnA_Enable = true;
int pwr_chna = 2;
bool bias_chnA = false;
unsigned long chna_freq = 1000;
void page_chnA() {
  lcd.clear();
  lcd.noCursor();
  lcd.setCursor(15, 1);
  lcd.write(byte(BACK_MENU));
  lcd.setCursor(13, 1);
  lcd.write(byte(BIAS_MENU));

  lcd.setCursor(0, 0);
  lcd.print(F("CHNA 1000hz 2mA"));
  lcd.setCursor(0, 1);
  lcd.print(F(" 001.00Mhz E"));

  lcd.setCursor(5, 0);
  char lfreq_char[5];

  sprintf(lfreq_char, "%04d", lffreq_chna);
  lcd.print(lfreq_char);

  lcd.setCursor(1, 1);
  char hfreq_char[7];
  dtostrf(hffreq_chna, 6, 2, hfreq_char);
  for (int i = 0; i < 7; i++)
    if (hfreq_char[i] == ' ')
      hfreq_char[i] = '0';  // Replace space with zero
  lcd.print(hfreq_char);

  lcd.setCursor(11, 1);
  chnA_Enable ? lcd.print("E") : lcd.print("D");

  lcd.setCursor(13, 1);
  bias_chnA ? lcd.print("B") : lcd.write(byte(BIAS_MENU));

  rot_select_button.tick();
  rot_mode_button.tick();
  int option_selected = -1;
  int selected_character = 0;

  lcd.setCursor(12, 0);
  lcd.print(pwr_chna);


  while (!(was_clicked(SELECT_SW, false) && option_selected == BACK_OPTION)) {
    // put your main code here, to run repeatedly:
    unsigned char rselect_event = rselect.process();
    unsigned char rmode_event = rmode.process();

    //play sound
    if (rselect_event || rmode_event && buzz_duration > 0) {
      digitalWrite(BUZZ_PIN, HIGH);
      delay(buzz_duration);
      digitalWrite(BUZZ_PIN, LOW);
    }

    if (was_clicked(MODE_SW, false) && option_selected == CHN_HFFREQ) {
      ++selected_character;
      if (selected_character == 3)
        ++selected_character;

      if (selected_character > 5)
        selected_character = 0;

      lcd.setCursor(1 + selected_character, 1);
      lcd.cursor();
    }

    if (was_clicked(SELECT_SW, false) && option_selected == CHN_ENABLE) {
      lcd.setCursor(11, 1);
      chnA_Enable = !chnA_Enable;
      chnA_Enable ? lcd.print("E") : lcd.print("D");
      chnA_Enable ? Si.enable(0) : Si.disable(0);
    }

    if (was_clicked(SELECT_SW, false) && option_selected == CHN_BIAS) {
      lcd.setCursor(13, 1);
      bias_chnA = !bias_chnA;
      bias_chnA ? lcd.print("B") : lcd.write(byte(BIAS_MENU));
      bias_chnA ? digitalWrite(BIAS_PIN1, HIGH) : digitalWrite(BIAS_PIN1, LOW);
    }

    if (rselect_event) {
      rselect_event == DIR_CW ? option_selected++ : option_selected--;
      if (option_selected < 0)
        option_selected = OPTIONS_CHNA;
      if (option_selected > OPTIONS_CHNA)
        option_selected = 0;

      lcd.noCursor();
      lcd.setCursor(4, 0);
      lcd.print(" ");
      lcd.setCursor(0, 1);
      lcd.print(" ");
      lcd.setCursor(10, 1);
      lcd.print(" ");
      lcd.setCursor(12, 1);
      lcd.print(" ");
      lcd.setCursor(11, 0);
      lcd.print(" ");

      switch (option_selected) {
        case CHN_LFFREQ:
          lcd.setCursor(4, 0);
          lcd.write(byte(RIGHT_ARW));
          break;

        case CHN_HFFREQ:
          lcd.setCursor(0, 1);
          lcd.write(byte(RIGHT_ARW));
          lcd.setCursor(1 + selected_character, 1);
          lcd.cursor();
          break;

        case CHN_ENABLE:
          lcd.setCursor(10, 1);
          lcd.write(byte(RIGHT_ARW));
          break;

        case CHN_PWR:
          lcd.setCursor(11, 0);
          lcd.write(byte(RIGHT_ARW));
          break;

        case CHN_BIAS:
          lcd.setCursor(12, 1);
          lcd.write(byte(RIGHT_ARW));
          break;

        case BACK_OPTION:
          lcd.setCursor(15, 1);
          lcd.cursor();
          break;

        default:
          break;
      }
    }

    if (rmode_event) {
      switch (option_selected) {
        case CHN_LFFREQ:
          lcd.setCursor(5, 0);
          rmode_event == DIR_CW ? lffreq_chna += 10 : lffreq_chna -= 10;
          if (lffreq_chna < 0)
            lffreq_chna = 0;
          if (lffreq_chna > 9999)
            lffreq_chna = 9999;
          sprintf(lfreq_char, "%04d", lffreq_chna);
          lcd.print(lfreq_char);

          if (chnA_Enable) {
            chna_freq = lffreq_chna + (hffreq_chna*1000000);
            Si.setFreq(0, chna_freq);
            Si.enable(0);
          }
          break;

        case CHN_HFFREQ:
          lcd.setCursor(1, 1);
          if (selected_character <= 2)
            rmode_event == DIR_CW ? hffreq_chna += pow(10, (2 - selected_character)) : hffreq_chna -= pow(10, (2 - selected_character));
          else
            rmode_event == DIR_CW ? hffreq_chna += pow(10, (3 - selected_character)) : hffreq_chna -= pow(10, (3 - selected_character));
          if (hffreq_chna < 0)
            hffreq_chna = 0;
          if (hffreq_chna > 999.99)
            hffreq_chna = 999.99;

          formatfloat(hffreq_chna, 5, 2, hfreq_char);
          lcd.print(hfreq_char);
          lcd.setCursor(1 + selected_character, 1);
          lcd.cursor();

          if (chnA_Enable) {
            chna_freq = lffreq_chna + (hffreq_chna *1000000);
            Si.setFreq(0, chna_freq);
            Si.enable(0);
          }
          break;

        case CHN_ENABLE:
          lcd.setCursor(10, 1);
          lcd.write(byte(RIGHT_ARW));
          break;

        case CHN_PWR:
          lcd.setCursor(12, 0);
          rmode_event == DIR_CW ? pwr_chna += 2 : pwr_chna -= 2;
          if (pwr_chna > 8)
            pwr_chna = 2;
          if (pwr_chna < 2)
            pwr_chna = 8;
          lcd.print(pwr_chna);
          if (pwr_chna == 2) {
            Si.setPower(0, SIOUT_2mA);
          } else if (pwr_chna == 4) {
            Si.setPower(0, SIOUT_4mA);
          } else if (pwr_chna == 6) {
            Si.setPower(0, SIOUT_6mA);
          } else if (pwr_chna == 8) {
            Si.setPower(0, SIOUT_8mA);
          }
          break;

        case CHN_BIAS:
          lcd.setCursor(12, 1);
          lcd.write(byte(RIGHT_ARW));
          break;

        case BACK_OPTION:
          lcd.setCursor(15, 1);
          lcd.cursor();
          break;

        default:
          break;
      }
    }


    switch_sel_status = 0;
    switch_mode_status = 0;
    rot_select_button.tick();
    rot_mode_button.tick();
  }
  switch_sel_status = 0;
  switch_mode_status = 0;
}


#define OPTIONS_CHNB 4
#define PWR_CHNB 3

int lffreq_chnb = 1000;
float hffreq_chnb = 1;
bool chnB_Enable = true;
int pwr_chnb = 2;
bool bias_chnB = false;
unsigned long chnb_freq = 1000;
void page_chnB() {
  lcd.clear();
  lcd.noCursor();
  lcd.setCursor(15, 1);
  lcd.write(byte(BACK_MENU));

  lcd.setCursor(0, 0);
  lcd.print(F("CHNB 1000hz 2mA"));
  lcd.setCursor(0, 1);
  lcd.print(F(" 001.00Mhz E"));

  lcd.setCursor(5, 0);
  char lfreq_char[5];
  sprintf(lfreq_char, "%04d", lffreq_chnb);
  lcd.print(lfreq_char);

  lcd.setCursor(1, 1);
  char hfreq_char[7];
  dtostrf(hffreq_chnb, 6, 2, hfreq_char);
  for (int i = 0; i < 7; i++)
    if (hfreq_char[i] == ' ')
      hfreq_char[i] = '0';  // Replace space with zero
  lcd.print(hfreq_char);

  lcd.setCursor(11, 1);
  chnB_Enable ? lcd.print("E") : lcd.print("D");


  rot_select_button.tick();
  rot_mode_button.tick();
  int option_selected = -1;
  int selected_character = 0;

  lcd.setCursor(12, 0);
  lcd.print(pwr_chnb);


  while (!(was_clicked(SELECT_SW, false) && option_selected == BACK_OPTION)) {
    // put your main code here, to run repeatedly:
    unsigned char rselect_event = rselect.process();
    unsigned char rmode_event = rmode.process();

    //play sound
    if (rselect_event || rmode_event && buzz_duration > 0) {
      digitalWrite(BUZZ_PIN, HIGH);
      delay(buzz_duration);
      digitalWrite(BUZZ_PIN, LOW);
    }

    if (was_clicked(MODE_SW, false) && option_selected == CHN_HFFREQ) {
      ++selected_character;
      if (selected_character == 3)
        ++selected_character;

      if (selected_character > 5)
        selected_character = 0;

      lcd.setCursor(1 + selected_character, 1);
      lcd.cursor();
    }

    if (was_clicked(SELECT_SW, false) && option_selected == CHN_ENABLE) {
      lcd.setCursor(11, 1);
      chnB_Enable = !chnB_Enable;
      chnB_Enable ? lcd.print("E") : lcd.print("D");
      chnB_Enable ? Si.enable(2) : Si.disable(2);
    }

    if (rselect_event) {
      rselect_event == DIR_CW ? option_selected++ : option_selected--;
      if (option_selected < 0)
        option_selected = OPTIONS_CHNB;
      if (option_selected > OPTIONS_CHNB)
        option_selected = 0;

      lcd.noCursor();
      lcd.setCursor(4, 0);
      lcd.print(" ");
      lcd.setCursor(0, 1);
      lcd.print(" ");
      lcd.setCursor(10, 1);
      lcd.print(" ");
      lcd.setCursor(12, 1);
      lcd.print(" ");
      lcd.setCursor(11, 0);
      lcd.print(" ");

      switch (option_selected) {
        case CHN_LFFREQ:
          lcd.setCursor(4, 0);
          lcd.write(byte(RIGHT_ARW));
          break;

        case CHN_HFFREQ:
          lcd.setCursor(0, 1);
          lcd.write(byte(RIGHT_ARW));
          lcd.setCursor(1 + selected_character, 1);
          lcd.cursor();
          break;

        case CHN_ENABLE:
          lcd.setCursor(10, 1);
          lcd.write(byte(RIGHT_ARW));
          break;

        case PWR_CHNB:
          lcd.setCursor(11, 0);
          lcd.write(byte(RIGHT_ARW));
          break;


        case BACK_OPTION:
          lcd.setCursor(15, 1);
          lcd.cursor();
          break;

        default:
          break;
      }
    }

    if (rmode_event) {
      switch (option_selected) {
        case CHN_LFFREQ:
          lcd.setCursor(5, 0);
          rmode_event == DIR_CW ? lffreq_chnb += 10 : lffreq_chnb -= 10;
          if (lffreq_chnb < 0)
            lffreq_chnb = 0;
          if (lffreq_chnb > 9999)
            lffreq_chnb = 9999;
          sprintf(lfreq_char, "%04d", lffreq_chnb);
          lcd.print(lfreq_char);
          if (chnB_Enable) {
            chnb_freq = lffreq_chnb + (hffreq_chnb*1000000);
            Si.setFreq(2, chnb_freq);
            Si.enable(2);
          }
          break;

        case CHN_HFFREQ:
          lcd.setCursor(1, 1);
          if (selected_character <= 2)
            rmode_event == DIR_CW ? hffreq_chnb += pow(10, (2 - selected_character)) : hffreq_chnb -= pow(10, (2 - selected_character));
          else
            rmode_event == DIR_CW ? hffreq_chnb += pow(10, (3 - selected_character)) : hffreq_chnb -= pow(10, (3 - selected_character));
          if (hffreq_chnb < 0)
            hffreq_chnb = 0;
          if (hffreq_chnb > 999.99)
            hffreq_chnb = 999.99;

          formatfloat(hffreq_chnb, 5, 2, hfreq_char);
          lcd.print(hfreq_char);
          lcd.setCursor(1 + selected_character, 1);
          lcd.cursor();
          if (chnB_Enable) {
            chnb_freq = lffreq_chnb + (hffreq_chnb*1000000);
            Si.setFreq(2, chnb_freq);
            Si.enable(2);
          }

          break;

        case CHN_ENABLE:
          lcd.setCursor(10, 1);
          lcd.write(byte(RIGHT_ARW));
          break;

        case PWR_CHNB:
          lcd.setCursor(12, 0);
          rmode_event == DIR_CW ? pwr_chnb += 2 : pwr_chnb -= 2;
          if (pwr_chnb > 8)
            pwr_chnb = 2;
          if (pwr_chnb < 2)
            pwr_chnb = 8;
          lcd.print(pwr_chnb);
          if (pwr_chnb == 2) {
            Si.setPower(2, SIOUT_2mA);
          } else if (pwr_chnb == 4) {
            Si.setPower(2, SIOUT_4mA);
          } else if (pwr_chnb == 6) {
            Si.setPower(2, SIOUT_6mA);
          } else if (pwr_chnb == 8) {
            Si.setPower(2, SIOUT_8mA);
          }

          break;



        case BACK_OPTION:
          lcd.setCursor(15, 1);
          lcd.cursor();
          break;

        default:
          break;
      }
    }


    switch_sel_status = 0;
    switch_mode_status = 0;
    rot_select_button.tick();
    rot_mode_button.tick();
  }
  switch_sel_status = 0;
  switch_mode_status = 0;
}

#define OPTIONS_CHNC 3
#define DUTY_C 0
#define FREQ_C 1
#define ENABLE_C 2
#define BACK_OPTION 3
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
void loop() {

  lcd.clear();
  int sel_option = options_page();
  lcd.clear();
  switch (sel_option) {
    case PAGE_CHNA:
      page_chnA();
      break;

    case PAGE_CHNB:
      page_chnB();
      break;

    case PAGE_CHNC:
      page_chnC();
      break;

    case PAGE_CHND:
      page_chnD();
      break;

    default:
      break;
  }
}

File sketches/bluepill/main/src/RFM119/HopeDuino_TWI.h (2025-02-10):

/*
 * THE FOLLOWING FIRMWARE IS PROVIDED: 
 *  (1) "AS IS" WITH NO WARRANTY; 
 *  (2) TO ENABLE ACCESS TO CODING INFORMATION TO GUIDE AND FACILITATE CUSTOMER.
 * CONSEQUENTLY, HopeRF SHALL NOT BE HELD LIABLE FOR ANY DIRECT, INDIRECT OR
 * CONSEQUENTIAL DAMAGES WITH RESPECT TO ANY CLAIMS ARISING FROM THE CONTENT
 * OF SUCH FIRMWARE AND/OR THE USE MADE BY CUSTOMERS OF THE CODING INFORMATION
 * CONTAINED HEREIN IN CONNECTION WITH THEIR PRODUCTS.
 * 
 * Copyright (C) HopeRF
 *
 * website: www.HopeRF.com
 *          www.HopeRF.cn 
 */

/*! 
 * file       HopeDuino_TWI.cpp
 * brief      for HopeRF's EVB to use config soft TWI port
 * hardware   HopeRF's EVB
 *            
 *
 * version    1.1
 * date       Jan 15 2015
 * author     QY Ruan
 */

 

#ifndef HopeDuino_TWI_h
	#define HopeDuino_TWI_h
	
	#ifndef F_CPU
		#define F_CPU 16000000UL	//HopeDuino use 16MHz Xo
	#endif	

	#define	TWI_SPEED	2			//the bigger the slow

	#ifndef	byte
		typedef unsigned char byte;
	#endif
	
	#ifndef word
		typedef unsigned int  word;
	#endif
	
	#ifndef lword
		typedef unsigned long lword;
	#endif

	#include "Arduino.h"

	/** Hardware brief **/

	/** Hardware brief **/    
	//PORTB						//DDRx		PORTx		PINx pin on nano - 12
	#define	_TCLK    PB13		// 1          1          0
	
	//PORTD
	#define	_TDAT	 PB12		// 1          0 pin on nano - 6

	#define	SetTCLK()	(digitalWrite(_TCLK,HIGH))
	#define	ClrTCLK()	(digitalWrite(_TCLK,LOW))
	
	#define	InputTDAT() (pinMode(_TDAT,INPUT))
	#define	OutputTDAT() (pinMode(_TDAT,OUTPUT))
	
	#define	SetTDAT()	(digitalWrite(_TDAT,HIGH))
	#define	ClrTDAT()	(digitalWrite(_TDAT,LOW))
	
	#define TDAT_H()	(digitalRead(_TDAT))
	#define	TDAT_L()	((digitalRead(_TDAT))==0)

	class twiClass
	{
	 public:
	 	void vTWIInit(void);							/** initialize TWI port **/
	 	void vTWIWrite(byte adr, byte dat);		
	 	byte bTWIRead(byte adr);
	 	void vTWIReset(void);
	 	
	 private:
	 	void vTWIWriteByte(byte dat);
	 	byte bTWIReadByte(void);
	};

#else
	#warning "HopeDuino_TWI.h have been defined!"

#endif 

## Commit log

2024-09-04 Added Tests
    [labRF-B_Cu.gbr, labRF-B_Mask.gbr, labRF-B_Paste.gbr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]
2024-09-10 328p schematics added
    [labRF.kicad_sch]
2024-09-11 Finieshed PCB Design
    [labRF-B_Cu.gbr, labRF-B_Mask.gbr, labRF-B_Paste.gbr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]
2024-09-12 Upgraded Schematic to 9V reference
    [328p_design-B_Cu.gbr, 328p_design-B_Mask.gbr, 328p_design-B_Paste.gbr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]
2024-09-13 Finished bluepill schematics
    [labRF.kicad_pcb, labRF.kicad_sch]
2024-09-13 Organised sections and uploaded schematics
    [328p_design-B_Cu.gbr, 328p_design-B_Mask.gbr, 328p_design-B_Paste.gbr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]
2024-09-14 Added blue pill code
    [bluepill_design.kicad_sch]
